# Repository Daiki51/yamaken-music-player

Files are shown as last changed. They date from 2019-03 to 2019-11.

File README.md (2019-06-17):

# YamakenMusicPlayer

「自動昼休み音楽プレイヤー (yamaken-music-player)」は毎日同じ時刻に音楽を再生するプレイヤーです。

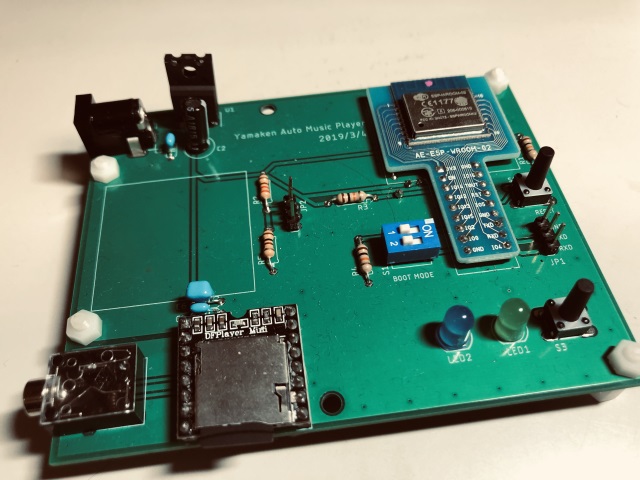
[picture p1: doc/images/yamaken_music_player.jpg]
YamakenMusicPlayer


GitHub: [https://github.com/Daiki51/yamaken-music-player](https://github.com/Daiki51/yamaken-music-player)

## 特徴
- 毎日同じ時刻に指定した時間(分)だけ音楽を再生
- 曲順は毎日シャッフル
- 音楽ファイルはSDカードから読み出し
- 手動での再生も対応
- NTPで時刻を同期しているため、時刻調整が不要
- IFTTTのサービスを利用し、音楽再生時にユーザーに通知可能
- Arduino IDEに対応したチップを使用しているため、振る舞いを簡単にカスタマイズ可

## ドキュメント

1. [再生する曲の変更]()
1. [制作方法]()
1. [ソフトウェアの書き込み方]()

## 回路図

詳細: [schematic.pdf](/circuit/YamakenMusicPlayer/schematic.pdf)

### A 電源回路部
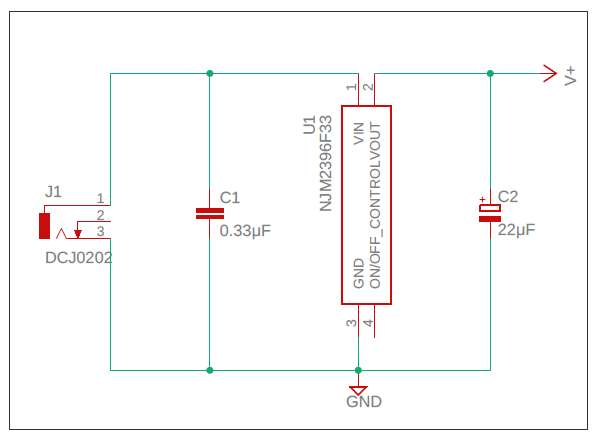
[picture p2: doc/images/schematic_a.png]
Schematic A


### B 制御IC部
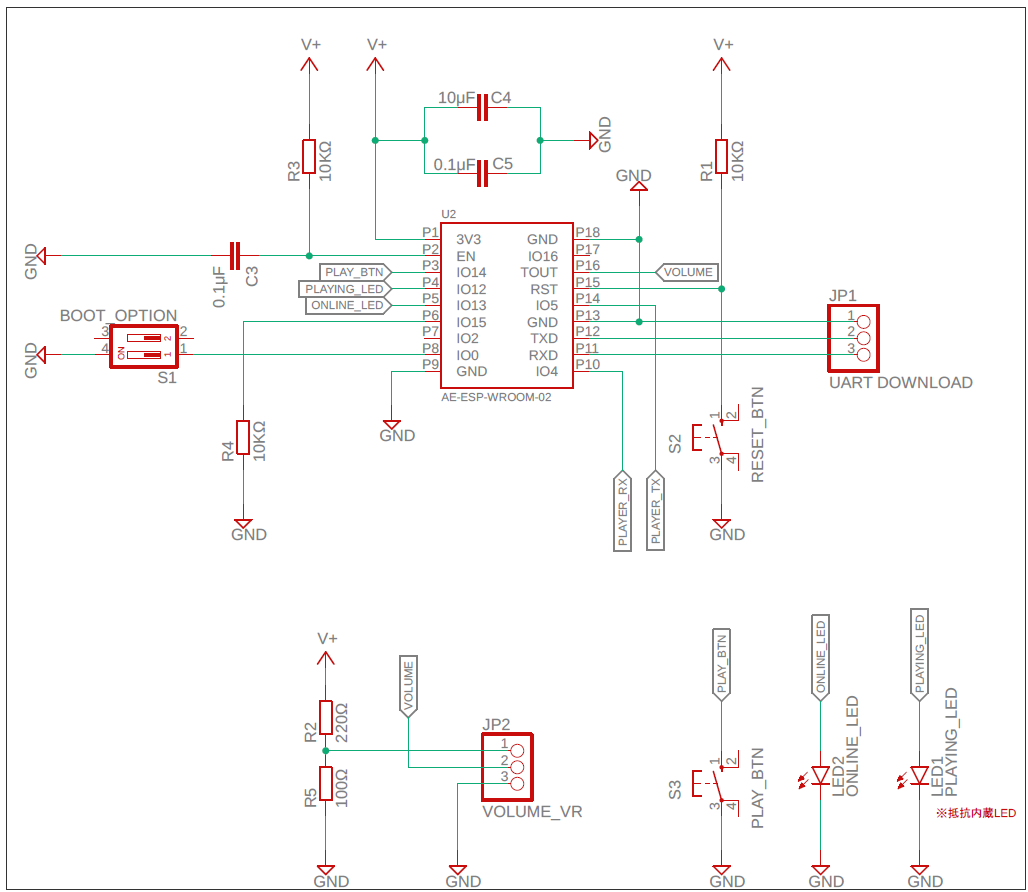
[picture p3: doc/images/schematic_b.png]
Schematic B


### C プレイヤーIC部
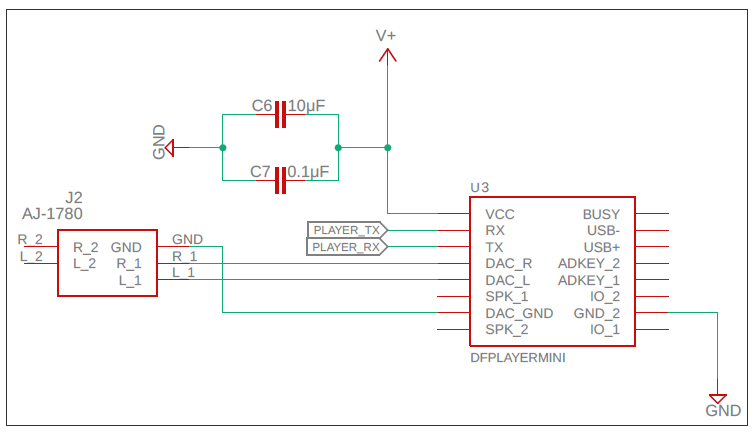
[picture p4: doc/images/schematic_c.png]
Schematic C


## 部品表

| 記号 | 品名 | 個数 | 備考 |
|---|---|---|---|
| U1 | NJM2396F33 | 1 | 定電圧リニアレギュレータ |
| U2 | AE-ESP-WROOM-02 | 1 | Wi-Fiモジュール (制御ICとして利用) |
| U3 | DFR0299 (DFPlayer Mini) | 1 | MP3モジュール |
| J1 | MJ-179PH | 1 | 2.1mm標準DCジャック |
| J2 | AJ-1780 | 1 | 3.5mmステレオミニジャック |
| R1, R3, R4 | 10kΩ | 3 | 1/4W 炭素皮膜抵抗　表示「茶黒橙金」 |
| R2 | 220Ω | 1 | 1/4W 炭素皮膜抵抗　表示「赤赤茶金」 |
| R5 | 100Ω | 1 | 1/4W 炭素皮膜抵抗　表示「茶黒茶金」 |
| C1 | 0.33μF | 1 | セラミックコンデンサ |
| C2 | 22μF | 1 | 電解コンデンサ |
| C3, C5, C7 | 0.1μF | 3 | セラミックコンデンサ |
| C4, C6 | 10μF | 2 | セラミックコンデンサ |
| S1 | DIPスイッチ | 1 | ブートモード切り替えスイッチ |
| S2 | タクトスイッチ (赤) | 1 | リセットボタン |
| S3 | タクトスイッチ (白) | 1 | 再生ボタン |
| LED1 | 緑色LED | 1 | 抵抗内蔵LED |
| LED2 | 青色LED | 1 | 抵抗内蔵LED |
| JP1, JP2 | ピンヘッダ (3ピン) | 2 | 2.54mmピッチ シングルライン |
| | SH16K4B102L20KC | 1 | 小型ボリューム 1kΩB |
| | ABS-15 | 1 | 小型ボリューム用ツマミ |

## 部品配置図

詳細: [board.pdf](/circuit/YamakenMusicPlayer/board.pdf)

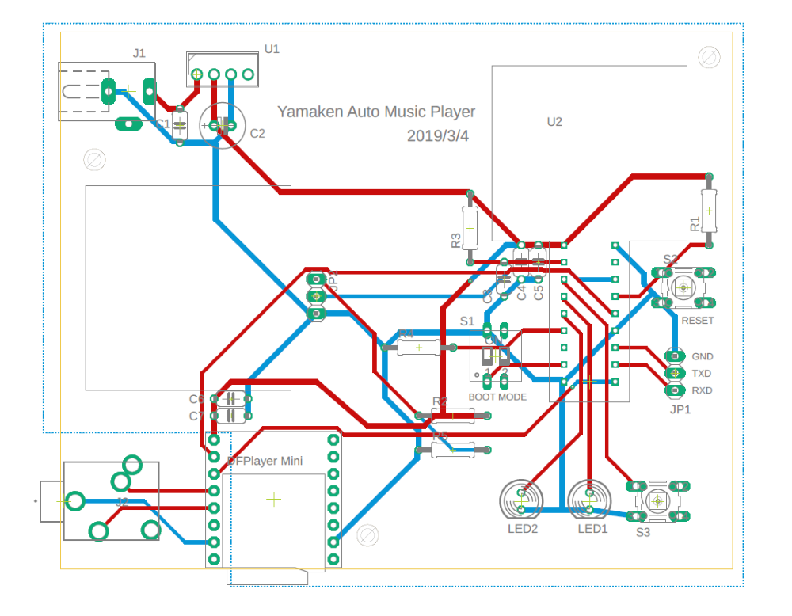
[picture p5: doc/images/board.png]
Board


## 依存ライブラリ

[DFPlayer - A Mini MP3 Player For Arduino](https://github.com/DFRobot/DFRobotDFPlayerMini)

[Arduino Client for MQTT (PubSubClient)](https://github.com/knolleary/pubsubclient)

[SerialCommand](https://github.com/kroimon/Arduino-SerialCommand)

[JLed - Advanced LED Library](https://github.com/jandelgado/jled)

[Switch library](https://github.com/avandalen/avdweb_Switch)

[Low-Pass-Filter](https://github.com/Billwilliams1952/Arduino-Cascadable-Low-Pass-Filter)

> 本プロジェクトのスケッチを動作させるためには、[Arduino Client for MQTT (PubSubClient)](https://github.com/knolleary/pubsubclient)と[SerialCommand](https://github.com/kroimon/Arduino-SerialCommand)の変更が必要です。

## ライセンス

[MIT](https://github.com/atom/atom/blob/master/LICENSE.md)

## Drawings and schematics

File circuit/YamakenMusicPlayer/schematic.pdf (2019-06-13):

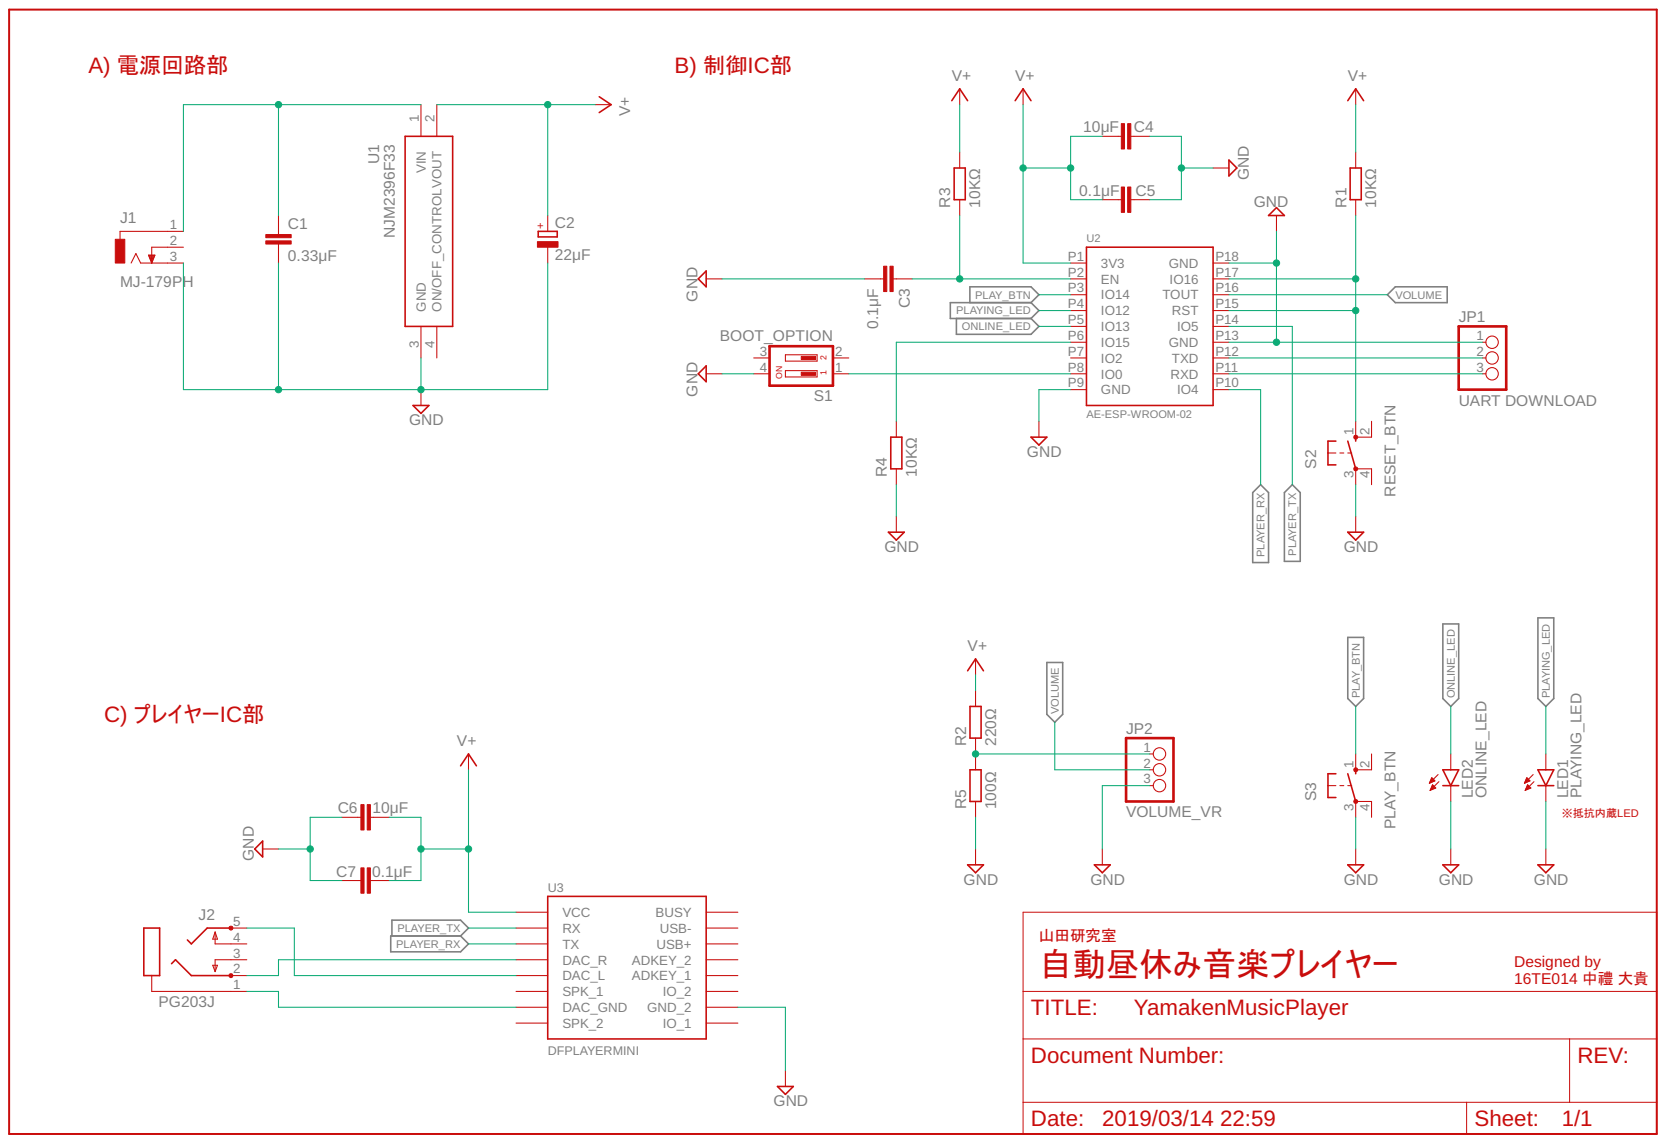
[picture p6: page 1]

Document Number: | REV:

Date: 2019/03/14 22:59 | Sheet: 1/1

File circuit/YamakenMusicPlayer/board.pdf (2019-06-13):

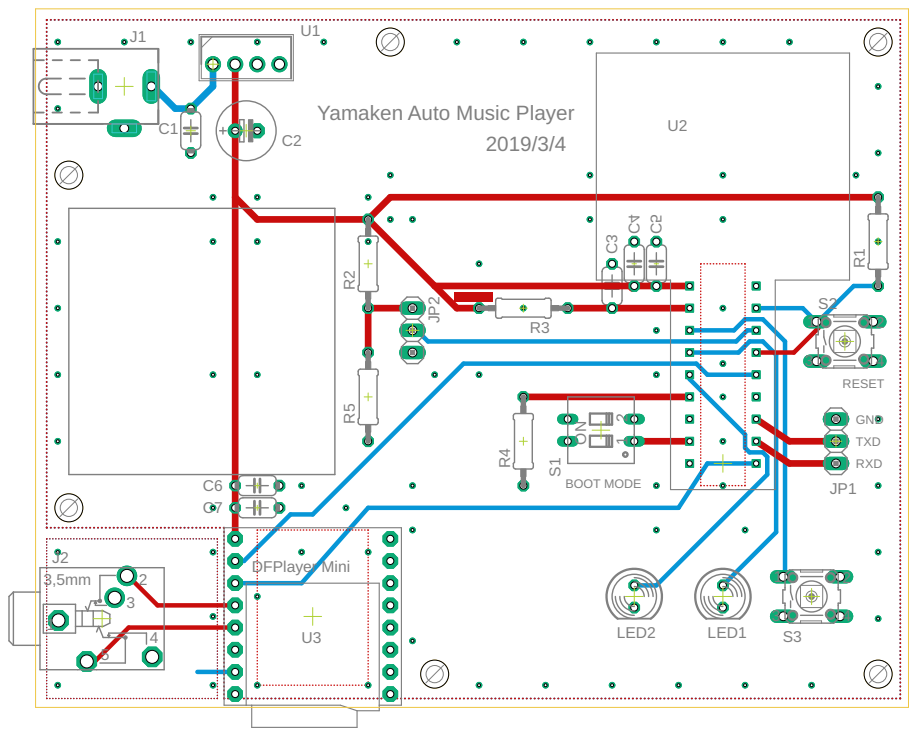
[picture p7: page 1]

Yamaken Auto Music Player

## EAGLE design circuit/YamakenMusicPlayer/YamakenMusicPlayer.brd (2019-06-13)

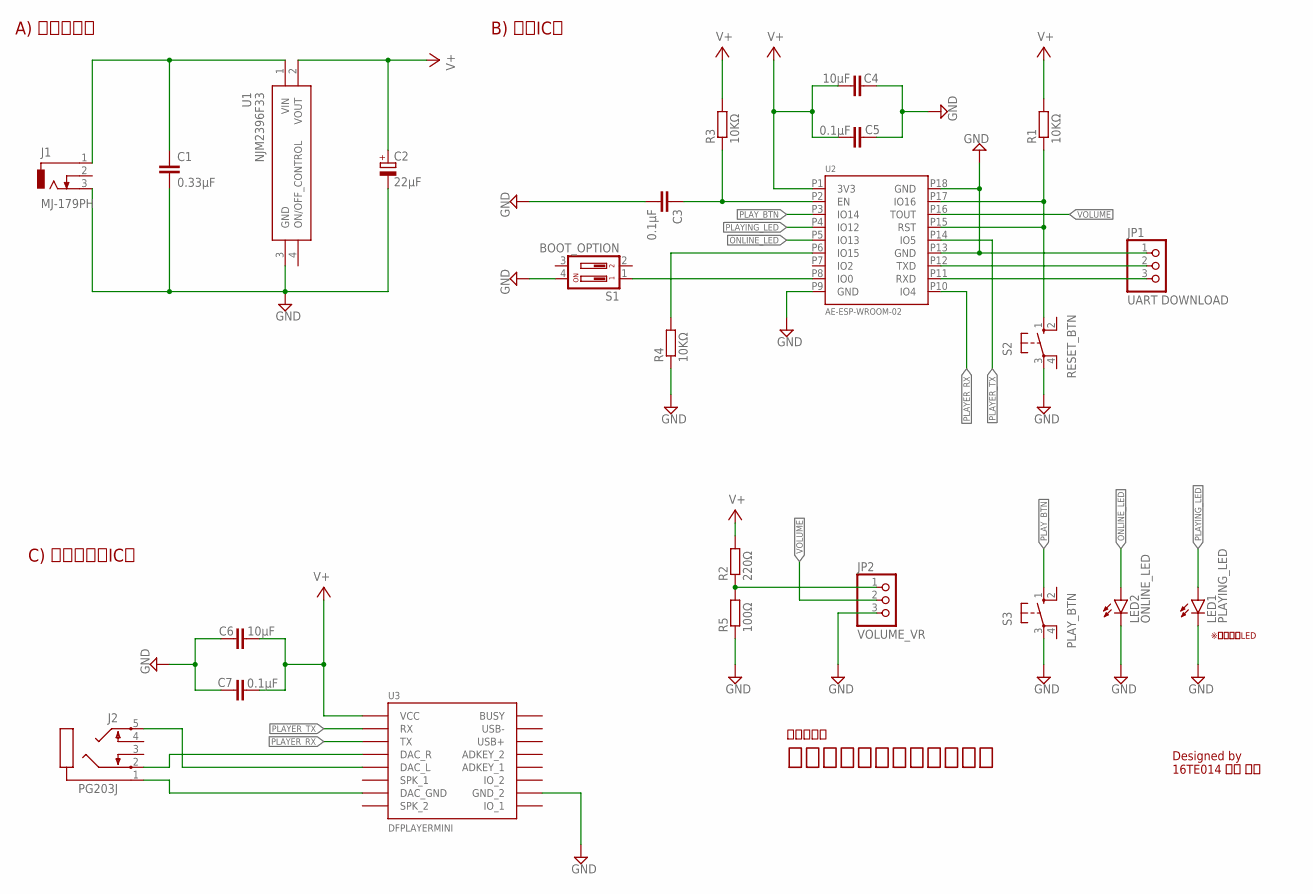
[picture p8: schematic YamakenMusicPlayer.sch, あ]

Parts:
C1: 0.33μF; C050-024X044
C2: 22μF; E2,5-7
C3, C5, C7: 0.1μF; C050-024X044
C4, C6: 10μF; C050-024X044
J1: MJ-179PH; DCJ0202
J2: PG203J
JP1: UART DOWNLOAD; 1X03
JP2: VOLUME_VR; 1X03
LED1: PLAYING_LED; LED5MM
LED2: ONLINE_LED; LED5MM
R1, R3, R4: 10KΩ; 0207/10
R2: 220Ω; 0207/10
R5: 100Ω; 0207/10
S1: BOOT_OPTION; DIP02YL
S2: RESET_BTN; B3F-10XX
S3: PLAY_BTN; B3F-10XX
U1: NJM2396F33; TO254P480X1000X1900-4P
U2: AE-ESP-WROOM-02
U3: DFPLAYERMINI

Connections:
+12V: C1.1, J1.1, U1.1 (VIN)
DAC_GND: J2.1, U3.GND_1 (DAC_GND)
DAC_R: J2.2, U3.DAC_R
GND: C1.2, C2.-, C3.2, C4.1, C5.1, C6.1, C7.1, J1.3, JP1.1, JP2.3, LED1.K (C), LED2.K (C), R4.1, R5.1, S1.4, S2.3, S3.3, U1.3 (GND), U2.P9 (GND), U2.P13 (GND), U2.P18 (GND), U3.GND_2
unnamed: R1.1, S2.1 (S), U2.P15 (RST), U2.P17 (IO16)
unnamed: J2.5, U3.DAC_L
unnamed: C3.1, R3.1, U2.P2 (EN)
unnamed: S1.1, U2.P8 (IO0)
unnamed: R4.2, U2.P6 (IO15)
unnamed: JP1.2, U2.P12 (TXD)
unnamed: JP1.3, U2.P11 (RXD)
unnamed: JP2.1, R2.1, R5.2
ONLINE_LED: LED2.A, U2.P5 (IO13)
PLAYER_RX: U2.P10 (IO4), U3.TX
PLAYER_TX: U2.P14 (IO5), U3.RX
PLAYING_LED: LED1.A, U2.P4 (IO12)
PLAY_BTN: S3.1 (S), U2.P3 (IO14)
V+: C2.+, C4.2, C5.2, C6.2, C7.2, R1.2, R2.2, R3.2, U1.2 (VOUT), U2.P1 (3V3), U3.VCC
VOLUME: JP2.2, U2.P16 (TOUT)

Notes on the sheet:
※抵抗内蔵LED
山田研究室
自動昼休み音楽プレイヤー
Designed by 16TE014 中禮 大貴
B) 制御IC部
A) 電源回路部
C) プレイヤーIC部

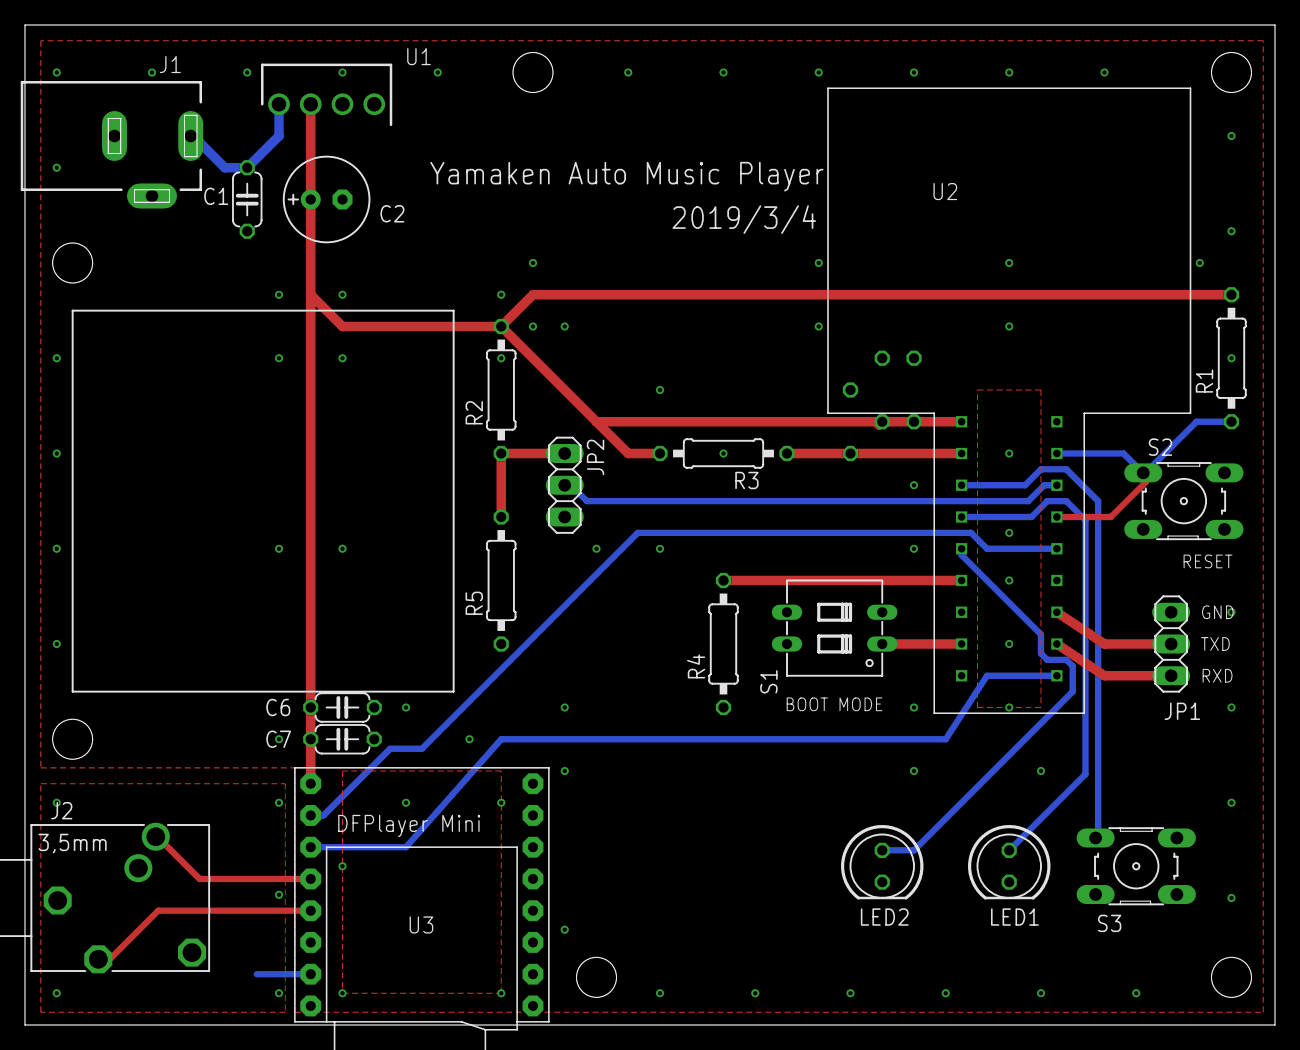
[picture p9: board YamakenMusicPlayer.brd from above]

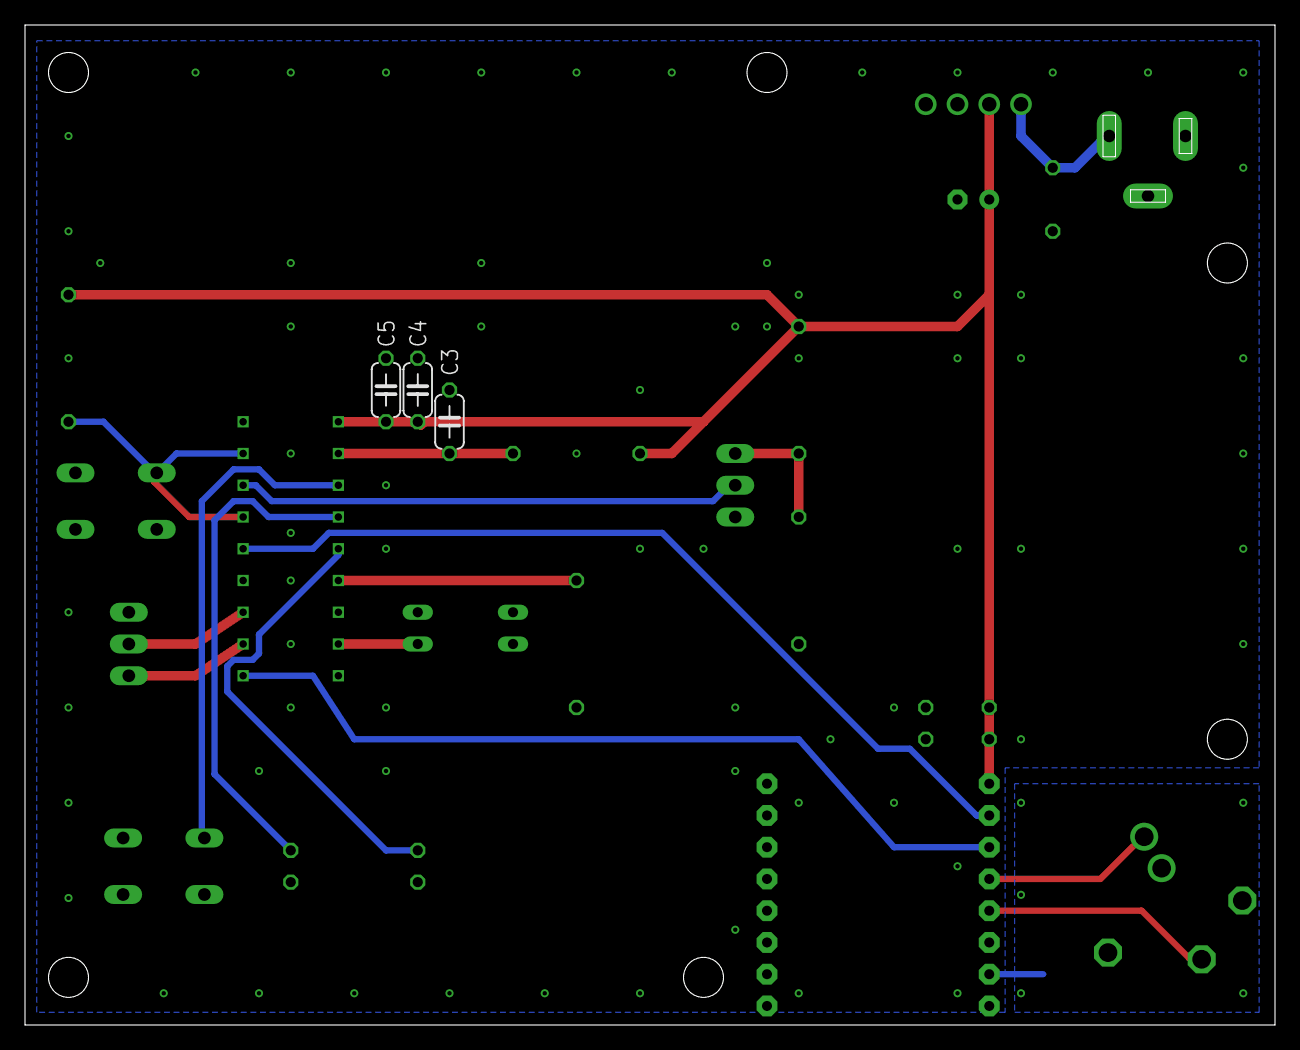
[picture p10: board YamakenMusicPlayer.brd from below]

Board: 2 copper layers, 100.0 x 80.0 mm, 24 parts (3 on the bottom side), 19 nets.

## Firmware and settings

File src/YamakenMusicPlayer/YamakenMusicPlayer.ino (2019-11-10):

#include <math.h>
#include <time.h>
#include <FS.h>
#include <ESP8266WiFi.h>
#include <ESP8266HTTPClient.h>
#include <Ticker.h>
#include <avdweb_Switch.h>
#include <jled.h>
#include <Lpf.h>
#include <ArduinoJson.h>
#include "src/Arduino-SerialCommand/SerialCommand.h"
#include "src/pubsubclient/src/PubSubClient.h"
#include "PlayerService.h"
#include "MusicScheduler.h"

//-------------------------------------
// 定数
//-------------------------------------
// ピン番号
const int8_t PLAYER_RX_PIN = 4;
const int8_t PLAYER_TX_PIN = 5;
const int PLAYING_LED_PIN = 12;
const int ONLINE_LED_PIN = 13;
const int PLAY_SW_PIN = 14;
const int VOLUME_PIN = A0;

// ボリュームセンサーのアナログ最大値
const int VOLUME_SENSOR_MAX = 1024;
const int VOLUME_SENSOR_MIN = 2;

// 日本標準時(+0900)
const int JST = 3600*9;

//-------------------------------------
// グローバル変数
//-------------------------------------

// DFPlayerとの通信を担当するクラス
PlayerService playerService(PLAYER_RX_PIN, PLAYER_TX_PIN);

// 定期的な再生スケジューリングを管理するクラス
MusicScheduler musicScheduler;

// ボタンとLED
Switch playButton(PLAY_SW_PIN);
JLed playingLed(PLAYING_LED_PIN);
JLed onlineLed(ONLINE_LED_PIN);

// 音量関係
int volume = -1;
LPF volumeFilter(0.2, false); // ボリュームのローパスフィルタ

// シリアル
SerialCommand sCmd; // シリアル通信でコマンドを処理するため

// 通信関係
WiFiClient wifiClient;
PubSubClient mqttClient(wifiClient);
bool isWifiConnecting = false;
bool isFirstConnect = true;

// 設定ストア(JSON形式)
StaticJsonDocument<1000> config;
bool isLoaded = false;

// タイマー割り込み用
//Ticker tickerUpdateSensorAndLed;
//Ticker tickerUpdatePlayer;
Ticker tickerCheckWiFi;

bool playButtonPushedFlag = false;
bool playerUpdateFlag = false;
bool wifiJustConnectedFlag = false;
bool isOnline = false;

// その他
int32_t loop_count = 0;

//-------------------------------------
// setup & loop
//-------------------------------------
void setup() {
  Serial.begin(115200);
  printBannerMessage();
  Serial.println("[INFO] Setup start");

  // ボリューム用のローパスフィルタを初期化
  volume = (int)round(30.0 * getRawVolume());
  volumeFilter.Reset(volume);

  // コマンドの登録
  sCmd.addCommand("HELP", helpCommandCallback);
  sCmd.addCommand("SET_WIFI", setWiFiCommandCallback);
  sCmd.addCommand("PLAY", playCommandCallback);
  sCmd.addCommand("STOP", stopCommandCallback);
  sCmd.addCommand("SLEEP", sleepCommandCallback);
  sCmd.setDefaultHandler(defaultCommandCallback);

  // 設定を読み込む
  SPIFFS.begin();
  loadConfig();

  // Wi-Fiに接続
  connectWiFi();
  configTime(JST, 0, "ntp.nict.jp", "ntp.jst.mfeed.ad.jp");

  // プレイヤーを初期化
  playerService.begin();
  playerService.onPlay(onPlayCallback);
  playerService.onStop(onStopCallback);
  playerService.onError(onErrorCallback);

  // タイマーの登録
//  tickerUpdateSensorAndLed.attach_ms(20, updateSensorAndLed);
//  tickerUpdatePlayer.attach_ms(20, updatePlayer);

  // スケジューラーを初期化
  musicScheduler.onStart(onStartCallback);
  musicScheduler.onEnd(onEndCallback);
  musicScheduler.bind(&playerService);
  musicScheduler.loadTask();

  Serial.println("[INFO] Ready");
}

// Wi-Fiに接続
void connectWiFi() {
  // LEDの点滅(スロー)を開始
  onlineLed.Breathe(1000).Forever();
  WiFi.mode(WIFI_STA);
  if (String((const char*)config["wifi"]["configure_ip"]) == "static") {
    // 固定IPアドレスの設定
    IPAddress ip_address;
    IPAddress dns;
    IPAddress gateway;
    IPAddress netmask;
    ip_address.fromString((const char*)config["wifi"]["ip_address"]);
    dns.fromString((const char*)config["wifi"]["dns"]);
    gateway.fromString((const char*)config["wifi"]["gateway"]);
    netmask.fromString((const char*)config["wifi"]["netmask"]);
    WiFi.config(ip_address, dns, gateway, netmask);
  }
  WiFi.begin((const char*)config["wifi"]["ssid"], (const char*)config["wifi"]["password"]);
  tickerCheckWiFi.attach_ms(100, checkWiFi);
  isWifiConnecting = true;
}

void loop() {
  sCmd.readSerial();
  if (playButtonPushedFlag) {
    // 再生ボタンが押された時
    if (!playerService.isPlaying()) {
      playerService.setRepeat(true);
      playerService.setShuffle(true);
      playerService.playFolder(config["music"]["default_folder"]);
    } else {
      playerService.stop();
    }
    playButtonPushedFlag = false;
  }
  if (playerUpdateFlag) {
    // プレイヤーの状態を更新する時
    playerService.update();
    playerService.setVolume(volume);
    musicScheduler.update();
    playerUpdateFlag = false;
  }
  if (wifiJustConnectedFlag) {
    // Wi-Fiの接続に成功した時
    wifiJustConnectedFlag = false;
    isWifiConnecting = false;
    isOnline = true;
    if (isFirstConnect) {
      Serial.println("[INFO] Wi-Fi connected");
    } else {
      Serial.println("[INFO] Wi-Fi reconnected");
    }
    Serial.print("  IP address: ");
    Serial.println(WiFi.localIP());
    Serial.print("  Time: ");
    Serial.println(getTimeStr());
  }
  if (!isWifiConnecting && WiFi.status() != WL_CONNECTED) {
    // Wi-Fiが何らかの理由で切断された時
    Serial.println("[WARN] Wi-Fi disconnected");
    isOnline = false;
    // Wi-Fiに再接続
    connectWiFi();
  }
  if (isOnline && !mqttClient.connected()) {
    // Wi-Fiに接続したがMQTTにまだ接続していない時
    // もしくはMQTTが何らかの理由で切断された時
    if (connectMQTT()) {
      Serial.println("[INFO] MQTT connected");
      if (isFirstConnect) {
        notifyEvent("startApp");
      } else {
        notifyEvent("reconnect");
      }
      isFirstConnect = false;
    } else {
      Serial.print("[ERROR] MQTT connection failed: ");
      Serial.println(mqttClient.state());
    }
  }
  if (loop_count % 5 == 0) {
    updateSensorAndLed();
    updatePlayer();
  }
  if (loop_count % 75000 == 0) { // 5分毎に生存報告
    notifyEvent("heartBeats");
  }
  mqttClient.loop();
  loop_count++;
  delay(4);
}

//-------------------------------------
// タイマー割り込みのコールバック
//-------------------------------------
void updateSensorAndLed() {
  playButton.poll();
  playingLed.Update();
  onlineLed.Update();
  float rawVolume = getRawVolume();
  volume = (int)round(30.0 * volumeFilter.NextValue(rawVolume));
  if (playButton.pushed()) {
    playButtonPushedFlag = true;
  }
}

void updatePlayer() {
  playerUpdateFlag = true;
}

void checkWiFi() {
  // Wi-Fiに接続したかどうか確認
  if (WiFi.status() != WL_CONNECTED) {
    return;
  }
  // 時刻が同期したかどうか確認
  time_t t = time(NULL);
  struct tm *tm;
  tm = localtime(&t);
  if (tm->tm_year + 1900 < 2019) {
    return;
  }
  tickerCheckWiFi.detach();
  onlineLed.On();
  musicScheduler.begin();
  wifiJustConnectedFlag = true;
}

//-------------------------------------
// プレイヤーのイベントコールバック
//-------------------------------------
void onPlayCallback(uint8_t folderNumber, uint8_t fileNumber) {
  Serial.print("[INFO] Play: ");
  Serial.print(folderNumber);
  Serial.print("-");
  Serial.println(fileNumber);
  playingLed.On();
  notifyPlay(folderNumber, fileNumber);
}

void onStopCallback() {
  Serial.println("[INFO] Stop");
  playingLed.Off();
  notifyEvent("stop");
}

void onErrorCallback(String message) {
  Serial.print("[ERROR] ");
  Serial.println(message);
  notifyError(message);
}

//-------------------------------------
// スケジューラーのイベントコールバック
//-------------------------------------
void onStartCallback() {
  Serial.println("[INFO] Start Task");
  notifyEvent("startTask");
}

void onEndCallback() {
  Serial.println("[INFO] End Task ");
  notifyEvent("endTask");
}

//-------------------------------------
// シリアルコマンド関連
//-------------------------------------
// 起動時のバナー表示
void printBannerMessage() {
  Serial.println(F(
    "\n"
    "━━━━━━━━━━━━━━━━━━━━━━━━━━━━━━━━━━\n"
    "■■   ■■                                          \n"
    " ■   ■                                             \n"
    "  ■ ■   Yamaken Music Player                                \n"
    "   ■     © 2019 Daiichi Institute of Technology Yamada's lab \n"
    "   ■                                         \n"
    "   ■                                         \n"
    "━━━━━━━━━━━━━━━━━━━━━━━━━━━━━━━━━━"
    ));
  Serial.println(F("Commands are available for this player."));
  Serial.println(F("Please enter HELP to see how to use the command."));
  Serial.println(F("このプレイヤーはコマンドが利用可能です。"));
  Serial.println(F("コマンドの使用方法を調べるにはHELPと入力してください。"));
  Serial.println(F("━━━━━━━━━━━━━━━━━━━━━━━━━━━━━━━━━━"));
}

// SET_WIFIコマンド
void setWiFiCommandCallback() {
  config["wifi"]["ssid"] = sCmd.next();
  config["wifi"]["password"] = sCmd.next();
  Serial.println("[LOG] Changed WiFi");
  Serial.print("  ssid: ");
  Serial.println((const char*)config["wifi"]["ssid"]);
  Serial.print("  Password: ");
  Serial.println((const char*)config["wifi"]["password"]);
  saveConfig();
}

// PLAYコマンド
void playCommandCallback() {
  char *folderNumberStr = sCmd.next();
  if (folderNumberStr == nullptr) {
    Serial.println(F("[ERROR] No arguments"));
    printCommandNavi();
    return;
  }
  char *fileNumberStr = sCmd.next();
  if (folderNumberStr == nullptr) {
    Serial.println(F("[ERROR] No arguments"));
    printCommandNavi();
    return;
  }
  int folderNumber = atoi(folderNumberStr);
  int fileNumber = atoi(fileNumberStr);
  playerService.playFile(folderNumber, fileNumber);
}

// STOPコマンド
void stopCommandCallback() {
  playerService.stop();
}

// SLEEPコマンド
void sleepCommandCallback() {
  char *secStr = sCmd.next();
  if (secStr == nullptr) {
    Serial.println(F("[ERROR] No arguments"));
    printCommandNavi();
    return;
  }
  int sec = atoi(secStr);
  ESP.deepSleep(sec * 1000 * 1000, WAKE_RF_DEFAULT);
  delay(1000);
}

// HELPコマンド
void helpCommandCallback() {
  Serial.println(F(
    "[INFO] Command List\n"
    "  HELP                          show this help message\n"
    "                                このヘルプを表示します\n"
    "  PLAY folderNum fileNum        play pecified music\n"
    "                                指定した音楽を再生します\n"
    "  STOP                          stop music\n"
    "                                再生を停止します\n"
    "  SLEEP sec                     sleep for a specified number of seconds.\n"
    "                                指定した秒数の間スリープします\n"
    "  SET_WIFI ssid pass            set Wi-Fi SSID & password\n"
    "                                接続するWi-FiのSSIDとパスワードを設定します\n"
    ));
}

// 不明のコマンド
void defaultCommandCallback(const char *cmd) {
  Serial.print(F("[ERROR] Unknown command: "));
  Serial.println(cmd);
  printCommandNavi();
}

void printCommandNavi() {
  Serial.println(F("  Please enter HELP to see how to use the command."));
  Serial.println(F("  コマンドの使用方法を調べるにはHELPと入力してください。"));
}

//-------------------------------------
// MQTT
//-------------------------------------

bool connectMQTT() {
  mqttClient.setServer((const char*)config["mqtt"]["hostname"], (int)config["mqtt"]["port"]);
  mqttClient.connect(config["mqtt"]["client_id"], config["mqtt"]["user_name"], NULL);
  if (!mqttClient.connected()) {
    return false;
  }
  mqttClient.setCallback(callback);
  mqttClient.subscribe(config["mqtt"]["receive_topic"]);
  return true;
}

// MQTTのPublishイベントを受け取るコールバック
void callback(char* topic, byte* payload, unsigned int length) {
  // 受け取ったJSON形式のペイロードをデコードする
  StaticJsonDocument<MQTT_MAX_PACKET_SIZE> json;
  deserializeJson(json, payload);
  char data_char[MQTT_MAX_PACKET_SIZE];
  strcpy(data_char, (const char*)json["data"]);
  deserializeJson(json, data_char);
  // コマンドを処理
  String command = json["command"];
  if (command == "play") {
    int folderNumber = json["folderNumber"];
    int fileNumber = json["fileNumber"];
    playerService.setRepeat(false);
    playerService.setShuffle(true);
    playerService.playFile(folderNumber, fileNumber);
  } else if (command == "playFolder") {
    int folderNumber = json["folderNumber"];
    playerService.setRepeat(false);
    playerService.setShuffle(true);
    playerService.playFolder(folderNumber);
  } else if (command == "stop") {
    playerService.stop();
  }
}

// イベントが発生したことを外部に通知する
void notifyEvent(const char *eventName) {
  StaticJsonDocument<MQTT_MAX_PACKET_SIZE> doc;
  auto json = doc.to<JsonObject>();
  json["event"] = eventName;
  notify(json);
}

// 「再生」イベントが発生したことを外部に通知する
void notifyPlay(uint8_t folderNumber, uint8_t fileNumber) {
  StaticJsonDocument<MQTT_MAX_PACKET_SIZE> doc;
  auto json = doc.to<JsonObject>();
  json["event"] = "play";
  json["params"]["folderNumber"] = folderNumber;
  json["params"]["fileNumber"] = fileNumber;
  notify(json);
}

// エラーが発生したことを外部に通知する
void notifyError(String errorMessage) {
  StaticJsonDocument<MQTT_MAX_PACKET_SIZE> doc;
  auto json = doc.to<JsonObject>();
  json["event"] = "error";
  json["params"]["message"] = errorMessage;
  notify(json);
}

// 外部に任意のデータを通知する
void notify(JsonObject &dataobj) {
  // Wi-Fiに接続したかどうか確認
  if (WiFi.status() != WL_CONNECTED) {
    return;
  }
  char data[MQTT_MAX_PACKET_SIZE];
  serializeJson(dataobj, data);
  StaticJsonDocument<MQTT_MAX_PACKET_SIZE> doc;
  auto json = doc.to<JsonObject>();
  json["data"] = data;
  char payload[MQTT_MAX_PACKET_SIZE];
  serializeJson(json, payload);
  bool success = mqttClient.publish(config["mqtt"]["sent_topic"], payload);
  if (!success) {
    Serial.println("[ERROR] MQTT Publish Error");
  }
}

//-------------------------------------
// その他
//-------------------------------------
// 設定を読み込む
void loadConfig() {
  File f = SPIFFS.open("/config.json", "r");
  deserializeJson(config, f);
  f.close();
}

// 設定を保存
void saveConfig() {
  File f = SPIFFS.open("/config.json", "w");
  serializeJson(config, f);
  f.close();
}

String getTimeStr(){
  time_t t = time(NULL);
  struct tm *tm;
  tm = localtime(&t);
  char s[22];
  sprintf(s, "%04d-%02d-%02d %02d:%02d:%02d",
    tm->tm_year + 1900, tm->tm_mon+1, tm->tm_mday,
    tm->tm_hour, tm->tm_min, tm->tm_sec);
  return String(s);
}

float getRawVolume() {
  return fmaxf(fminf(((float)analogRead(VOLUME_PIN) - VOLUME_SENSOR_MIN) / (VOLUME_SENSOR_MAX - VOLUME_SENSOR_MIN), 1.0), 0.0);
}

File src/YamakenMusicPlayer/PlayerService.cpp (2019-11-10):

#include <math.h>
#include "PlayerService.h"

static String getDetail(uint8_t type, int value);

static void defaultPlayCallback(uint8_t folderNumber, uint8_t fileNumber) {
  // do nothing
}

static void defaultStopCallback() {
  // do nothing
}

static void defaultErrorCallback(String message) {
  // do nothing
}

PlayerService::PlayerService(int8_t rx_pin, int8_t tx_pin) {
  _rx_pin = rx_pin;
  _tx_pin = tx_pin;
  _isPlaying = false;
  _isFading = false;
  _isWaiting = false;
  _volume = 30 / 2;
  _waitDuration = 2000;
  _queueIndex = 0;
  _repeat = false;
  _shuffle = false;
  _nextPlayRequested = false;
  for (int i = 0;  i < MAX_MUSIC_QUEUE; i++) {
    _playQueue[i][0] = -1;
    _playQueue[i][1] = -1;
  }
  _playCallback = defaultPlayCallback;
  _stopCallback = defaultStopCallback;
  _errorCallback = defaultErrorCallback;
}

void PlayerService::begin() {
  // DEF_playerと通信するためにSoftwareSerialを使用
  _software_serial.begin(9600, _rx_pin, _tx_pin);
  _player.begin(_software_serial);
  _player.stop();
  Serial.println(F("[INFO] DFPlayer Mini initialized"));
}

void PlayerService::playFile(uint8_t folderNumber, uint8_t fileNumber) {
  // キューに追加
  _queueIndex = 0;
  for (int i = 0; i < MAX_MUSIC_QUEUE; i++) {
    if (i > 0 && !_repeat) {
      _playQueue[i][0] = -1;
      _playQueue[i][1] = -1;
    } else {
      _playQueue[i][0] = folderNumber;
      _playQueue[i][1] = fileNumber;
    }
  }
  // キューを再生
  _playQueueOne();
}

void PlayerService::playFolder(uint8_t folderNumber) {
  // 曲順を決定
  int totalTrack;
  // トラックの数を取得 (エラーを考慮して数回試行する)
  for (int i = 0; i < 100; i++) {
    totalTrack = _player.readFileCountsInFolder(folderNumber);
    if (totalTrack != -1) {
      break;
    }
    delay(10);
  }
  if (totalTrack == -1) {
    Serial.println("[ERROR] readFileCountsInFolder = -1");
    while (true) {
      // プログラム終了
      delay(1000); 
    }
  }
  Serial.print("[INFO] Total Track: ");
  Serial.println(totalTrack);
  auto order = new uint8_t[totalTrack];
  for (int i = 0; i < totalTrack; i++) {
    order[i] = i + 1;
  }
  // シャッフル
  if (_shuffle) {
    for (int i = 0; i < totalTrack; i++) {
      int j = random(totalTrack);
      auto tmp = order[i];
      order[i] = order[j];
      order[j] = tmp;
    }
  }
  // キューに追加
  _queueIndex = 0;
  for (int i = 0; i < MAX_MUSIC_QUEUE; i++) {
    if (i >= totalTrack && !_repeat) {
      _playQueue[i][0] = -1;
      _playQueue[i][1] = -1;
    }
    _playQueue[i][0] = folderNumber;
    _playQueue[i][1] = order[i % totalTrack];
  }
  // キューを再生
  _playQueueOne();
}

void PlayerService::_playQueueOne() {
  auto folderNumber = _playQueue[_queueIndex][0];
  auto fileNumber = _playQueue[_queueIndex][1];
  if (folderNumber == -1) {
    // キューが空なので再生停止
    _isPlaying = false;
    _stopCallback();
    return;
  }
  _player.volume(0);
  _player.playFolder(folderNumber, fileNumber);
  _isPlaying = true;
  // フェードイン
  _isFading = true;
  for (int i = 0; i <= 30; i++) {
    _player.volume((int)round((float)_volume * i / 30));
    delay(20);
  }
  _isFading = false;
  _playCallback(folderNumber, fileNumber);
}

void PlayerService::_nextPlay() {
  _queueIndex = (_queueIndex + 1) % 0xff;
  _isWaiting = false;
  _playQueueOne();
}

void PlayerService::stop() {
  // フェードアウト
  _isFading = true;
  for (int i = 30; i >= 0; i--) {
    _player.volume((int)round((float)_volume * i / 30));
    delay(20);
  }
  _isFading = false;
  _player.pause();
  _isPlaying = false;
  _stopCallback();
}

void PlayerService::update() {
  while (_player.available()) { // 受信している情報がある場合
    uint8_t type = _player.readType();
    int value = _player.read();
    if (type == DFPlayerPlayFinished && !_isWaiting) {
      // 曲の最後まで到達したとき
      _isWaiting = true;
      _tickerNextPlay.once_ms(_waitDuration, [this]() {
        _nextPlayRequested = true;
      });
    } else if (type == DFPlayerError && value == FileMismatch && !_isWaiting) {
      // 存在しないファイルを再生しようとしたとき
      _isWaiting = true;
      _errorCallback(getDetail(type, value));
      _tickerNextPlay.once_ms(_waitDuration, [this]() {
        _nextPlayRequested = true;
      });
    } else {
      // エラーのとき
      _errorCallback(getDetail(type, value));
    }
  }
  if (_nextPlayRequested) {
    _nextPlayRequested = false;
    _nextPlay();
  }
}

void PlayerService::setVolume(int value) {
  if (value != _volume) {
    if (!_isFading) {
      _player.volume(value);
    }
    _volume = value;
  }
}

void PlayerService::setWaitDuration(int value) {
  _waitDuration = value;
}

void PlayerService::setRepeat(bool value) {
  _repeat = value;
}

void PlayerService::setShuffle(bool value) {
  _shuffle = value;
}

bool PlayerService::isPlaying() {
  return _isPlaying;
}

void PlayerService::onPlay(play_callback_t callback) {
  _playCallback = callback;
}

void PlayerService::onStop(stop_callback_t callback) {
  _stopCallback = callback;
}

void PlayerService::onError(error_callback_t callback) {
  _errorCallback = callback;
}

String getDetail(uint8_t type, int value) {
  switch (type) {
    case TimeOut:
      return F("Time Out!");
    case WrongStack:
      return F("Stack Wrong!");
    case DFPlayerCardInserted:
      return F("Card Inserted!");
    case DFPlayerCardRemoved:
      return F("Card Removed!");
    case DFPlayerCardOnline:
      return F("Card Online!");
    case DFPlayerPlayFinished:
      return String(F("Number:")) + value + F(" Play Finished!");
    case DFPlayerError:
      switch (value) {
        case Busy:
          return F("DFPlayerError: Card not found");
        case Sleeping:
          return F("DFPlayerError: Sleeping");
        case SerialWrongStack:
          return F("DFPlayerError: Get Wrong Stack");
        case CheckSumNotMatch:
          return F("DFPlayerError: Check Sum Not Match");
        case FileIndexOut:
          return F("DFPlayerError: File Index Out of Bound");
        case FileMismatch:
          return F("DFPlayerError: Cannot Find File");
        case Advertise:
          return F("DFPlayerError: In Advertise");
      }
      break;
  }
}

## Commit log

2019-03-04 基板上に表記を追加
    [YamakenMusicPlayer.brd]
2019-03-04 回路図画像を追加
2019-03-04 画像を加工
2019-03-04 表記の修正
    [YamakenMusicPlayer.brd, YamakenMusicPlayer.sch]
2019-03-04 Update schematic_c.png
    画像の修正
2019-03-04 U3の表記を追加
    [YamakenMusicPlayer.brd, YamakenMusicPlayer.sch]
2019-03-05 ファイルの差し替え
    [YamakenMusicPlayer.brd, YamakenMusicPlayer.sch]
2019-06-13 基板の修正
    [YamakenMusicPlayer.brd, YamakenMusicPlayer.sch]
2019-06-17 MQTTを使用するように変更
2019-06-17 トップ画像を差し替え
2019-06-17 ピン配置図を移動
    [esp8266_pin_arrangement.xlsx]
2019-06-17 依存ライブラリを自動でダウンロードするスクリプトを追加
2019-06-17 Wi-Fiを再接続する機能を実装
    また、設定をJSON形式で保存するように変更
2019-06-18 MQTTを再接続するように
